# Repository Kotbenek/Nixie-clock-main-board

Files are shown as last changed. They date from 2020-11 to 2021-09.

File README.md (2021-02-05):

# Nixie-clock-main-board
Main PCB of my Nixie clock

## Board overview

- 12V AC input
- Rectified, smoothed 12V AC output (around 16V DC, powering the [180V power supply](https://github.com/Kotbenek/180V-power-supply))
- ATmega32 AVR microcontroller as the heart of the Nixie clock
- Photoresistor input for PWM Nixie tubes dimming
- Two inputs for external buttons used for timezone setting (UTC offset): TIMEZONE- and TIMEZONE+
- GPS module connector (3.3V, ground and GPS_TX line) with power on/off capability
- 6P6C connector used for interfacing the [Nixie clock tubes driver](https://github.com/Kotbenek/Nixie-clock-tubes-driver) board
- AVR ISP connector for AVR programming

## Images

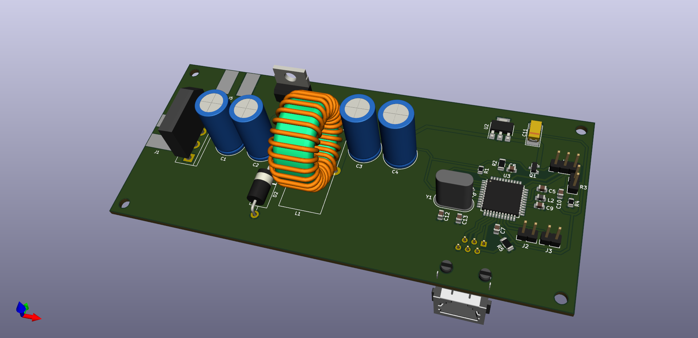
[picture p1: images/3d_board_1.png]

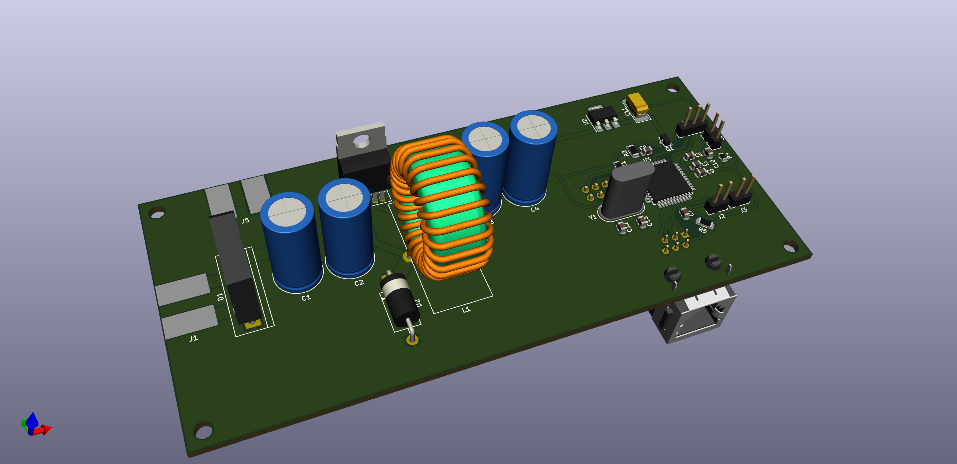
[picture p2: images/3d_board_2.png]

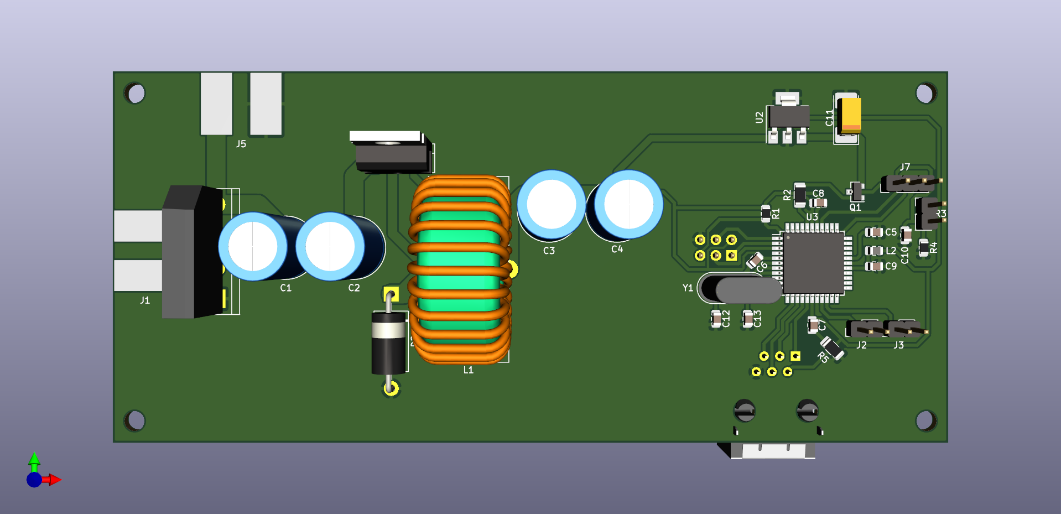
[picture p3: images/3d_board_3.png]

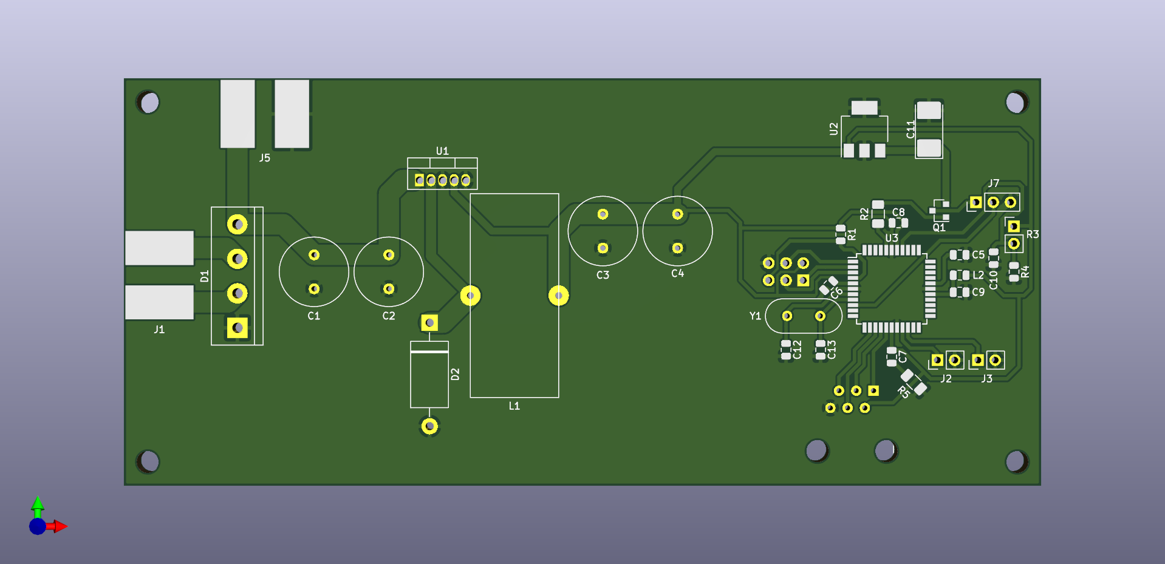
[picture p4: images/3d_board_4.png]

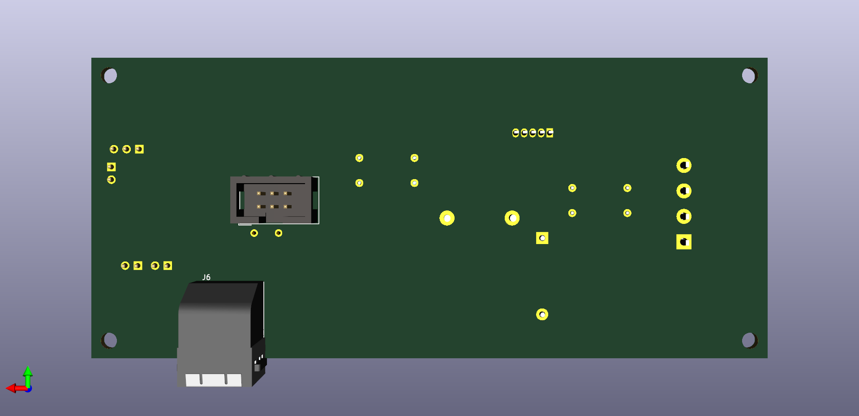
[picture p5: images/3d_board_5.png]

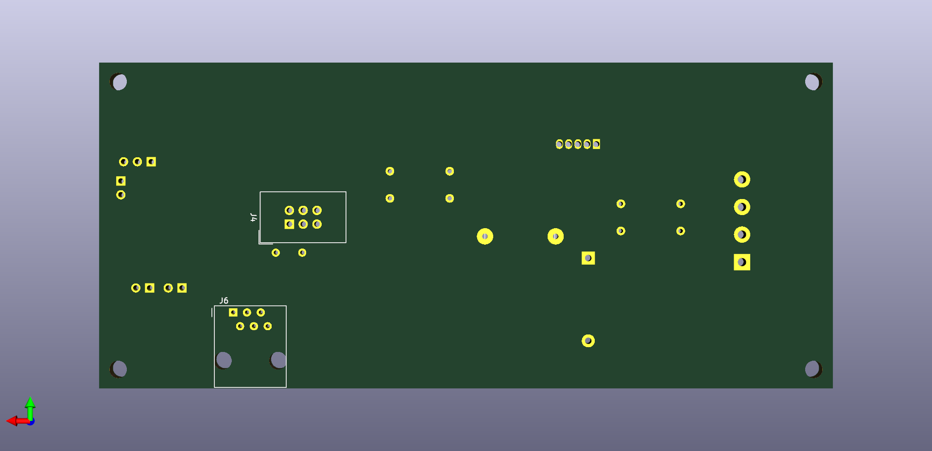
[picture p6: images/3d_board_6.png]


## External 3D models used in the PCB render

- [Bridge rectifier](https://grabcad.com/library/bridge-rectifier-kbp-case-1)
- [Toroid inductor](https://grabcad.com/library/inductor-toroid-25mm-1)
- [6P6C connector](https://grabcad.com/library/rj12-1)

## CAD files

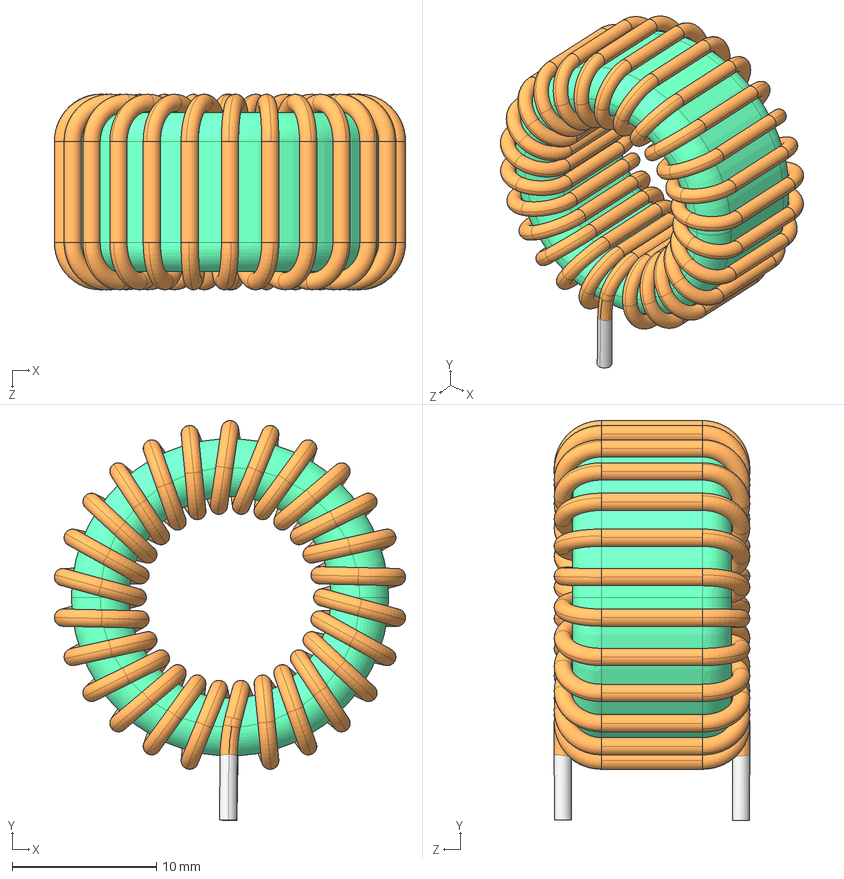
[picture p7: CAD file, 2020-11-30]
inductor.STEP
24.4 x 27.7 x 13.6 mm
櫻蠉錪1
櫻蠉錪3
櫻蠉錪2 x 50
櫻蠉錪4 x 2

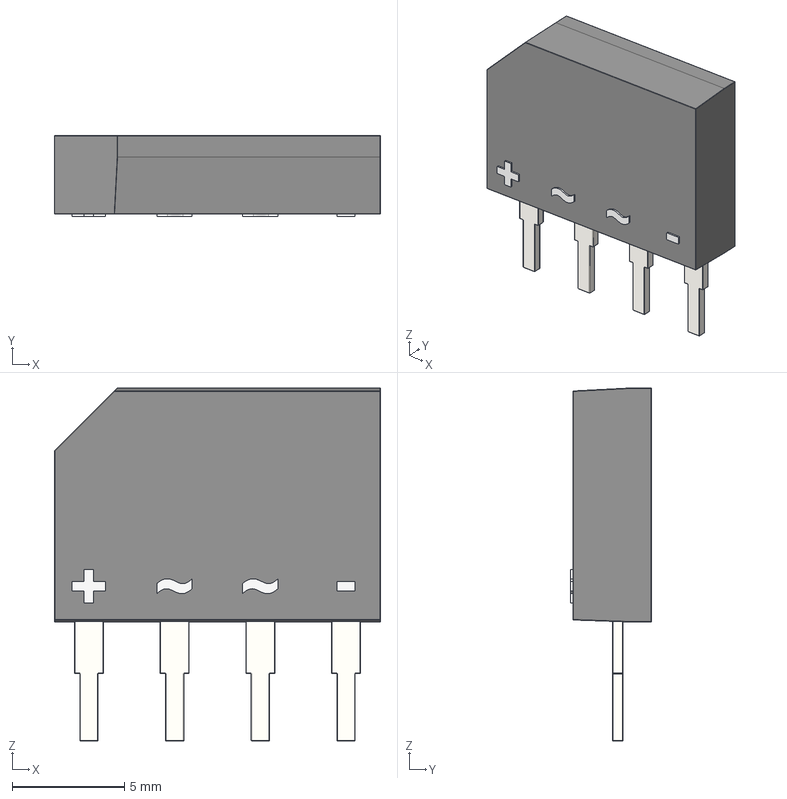
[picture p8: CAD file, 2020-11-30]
bridge.stp
14.5 x 3.60 x 15.7 mm

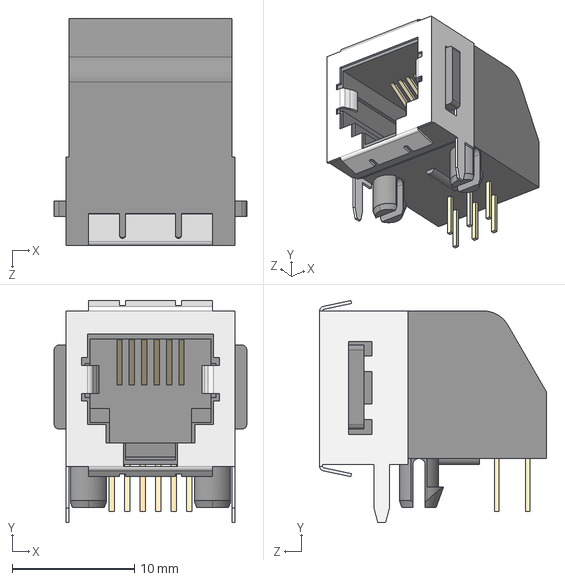
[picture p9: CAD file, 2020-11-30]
6p6c.stp
15.7 x 18.1 x 18.5 mm

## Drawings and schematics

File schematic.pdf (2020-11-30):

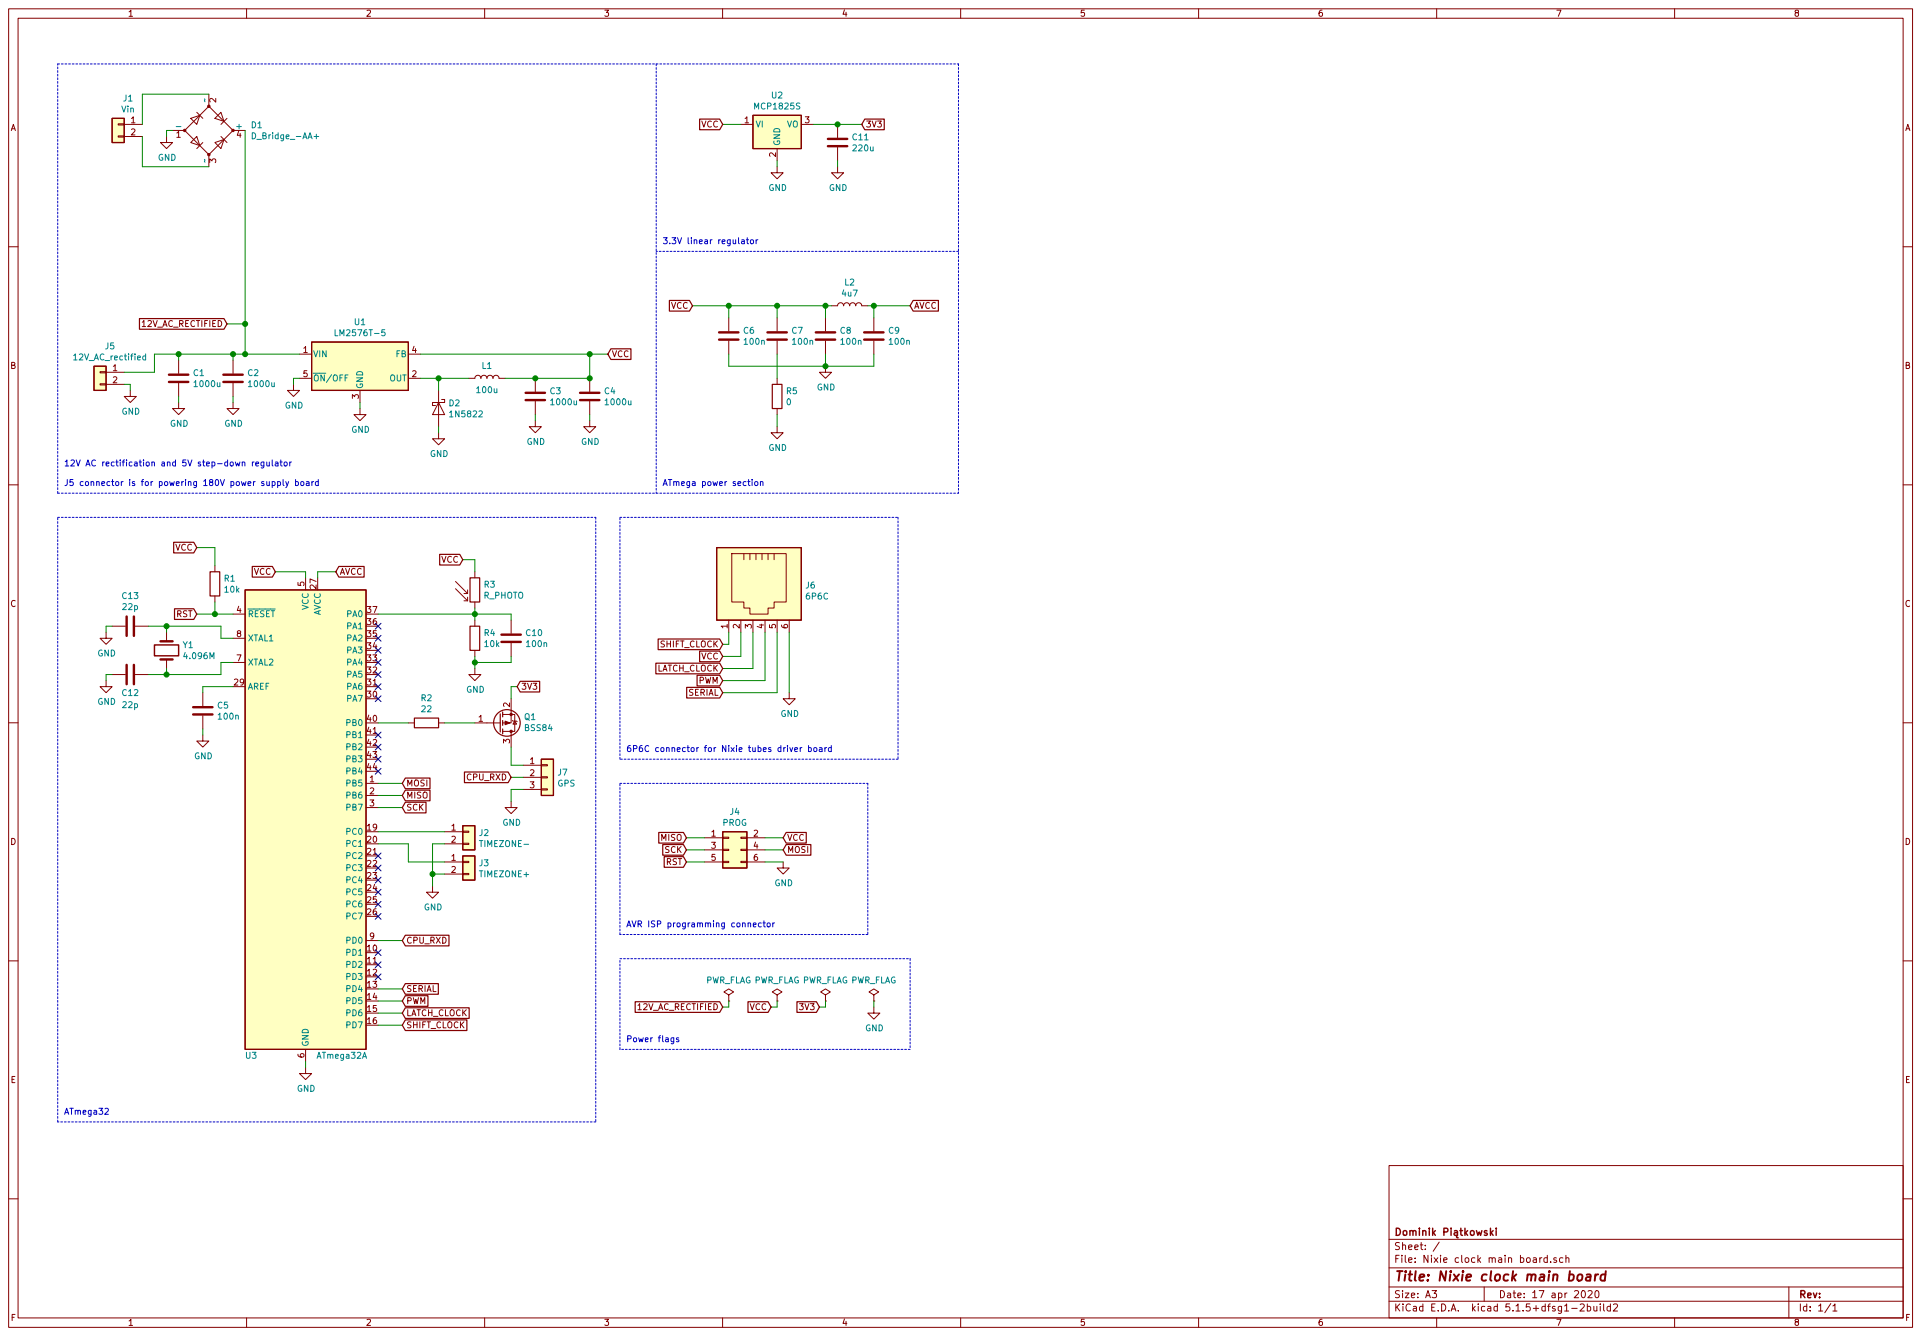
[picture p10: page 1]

3.3V linear regulator

ATmega power section | L2

12V AC rectification and 5V step-down regulator

J5 connector is for powering 180V power supply board

Power flags 6P6C connector for Nixie tubes driver board

AVR ISP programming connector

File: Nixie clock main board.sch Sheet: / Dominik Pitkowski

Id: 1/1 Title: Nixie clock main board

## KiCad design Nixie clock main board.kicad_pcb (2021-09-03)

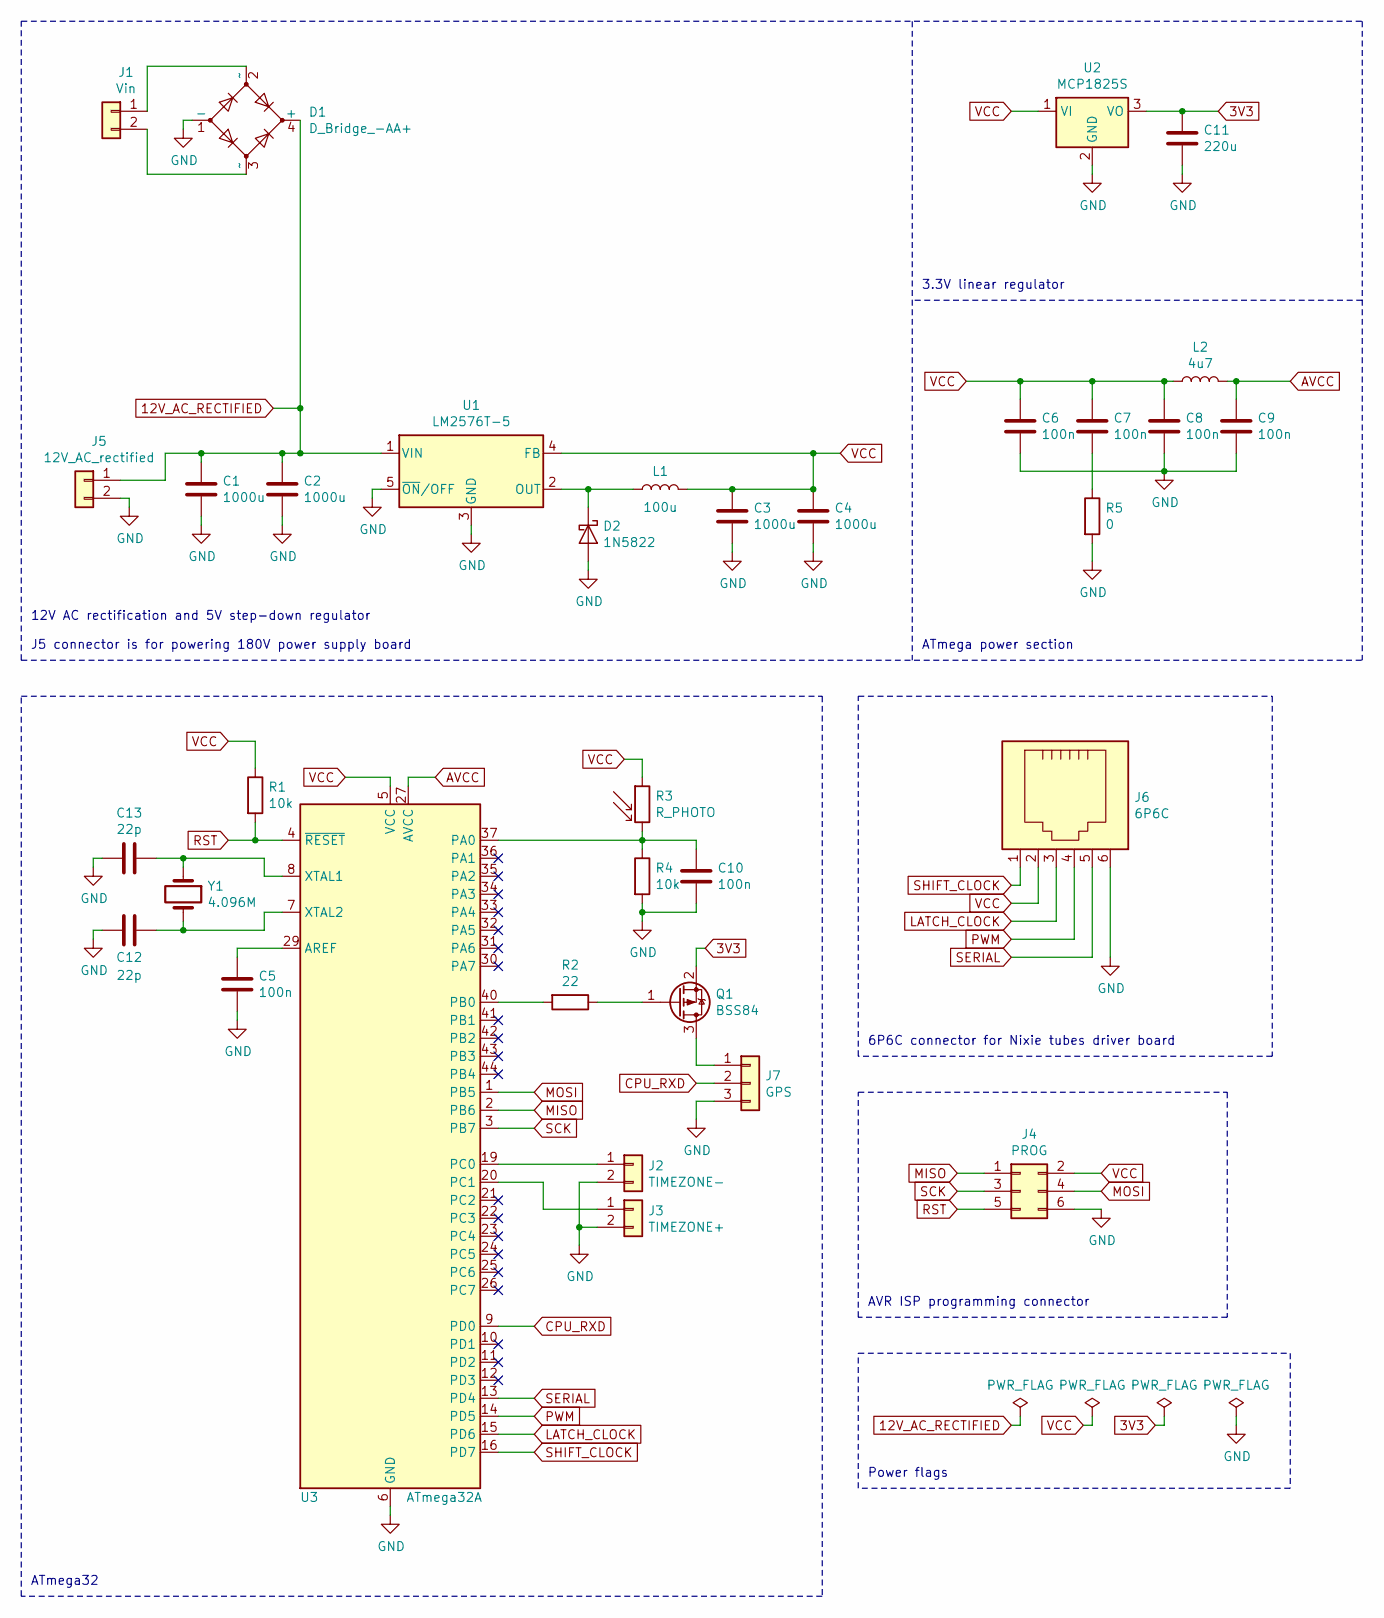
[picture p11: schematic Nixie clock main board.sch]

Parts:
C1, C2, C3, C4: 1000u; C_Radial_D10.0mm_H20.0mm_P5.00mm
C5, C6, C7, C8, C9, C10: 100n; C_0805_2012Metric
C11: 220u; CP_EIA-7132-28_AVX-C
C12, C13: 22p; C_0805_2012Metric
D1: D_Bridge_-AA+; TerminalBlock_bornier-4_P5.08mm
D2: 1N5822; D_DO-27_P15.24mm_Horizontal
J1: Vin; SolderWirePad_1x02_P3mm_10x5
J2: TIMEZONE-; PinHeader_1x02_P2.54mm_Vertical
J3: TIMEZONE+; PinHeader_1x02_P2.54mm_Vertical
J4: PROG; IDC-Header_2x03_P2.54mm_Vertical
J5: 12V_AC_rectified; SolderWirePad_1x02_P3mm_10x5
J6: 6P6C; RJ12_Amphenol_54601
J7: GPS; PinHeader_1x03_P2.54mm_Vertical
L1: 100u; L_Toroid_Vertical_L30mm_P13mm
L2: 4u7; L_0805_2012Metric
Q1: BSS84; SOT-23
R1, R4: 10k; R_0805_2012Metric
R2: 22; R_1206_3216Metric
R3: R_PHOTO; PinHeader_1x02_P2.54mm_Vertical
R5: 0; R_1206_3216Metric
U1: LM2576T-5; TO-220-5_Vertical
U2: MCP1825S; SOT-223-3_TabPin2
U3: ATmega32A; TQFP-44_10x10mm_P0.8mm
Y1: 4.096M; Crystal_HC49-U_Vertical

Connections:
3V3: C11.1, Q1.2 (S), U2.3 (VO)
12V_AC_RECTIFIED: C1.1, C2.1, D1.4 (+), J5.1, U1.1 (VIN)
AVCC: C9.1, L2.2, U3.27 (AVCC)
CPU_RXD: J7.2, U3.9 (PD0)
GND: C1.2, C2.2, C3.2, C4.2, C5.2, C6.2, C8.2, C9.2, C10.2, C11.2, C12.2, C13.2, D1.1 (-), D2.2 (A), J2.2, J3.2, J4.6, J5.2, J6.6, J7.3, R4.2, R5.2, U1.3 (GND), U1.5 (~ON~/OFF), U2.2 (GND), U3.6 (GND), U3.18 (GND), U3.28 (GND), U3.39 (GND)
LATCH_CLOCK: J6.3, U3.15 (PD6)
MISO: J4.1, U3.2 (PB6)
MOSI: J4.4, U3.1 (PB5)
unnamed: C5.1, U3.29 (AREF)
unnamed: C7.2, R5.1
unnamed: C10.1, R3.2, R4.1, U3.37 (PA0)
unnamed: C12.1, U3.7 (XTAL2), Y1.2
unnamed: C13.1, U3.8 (XTAL1), Y1.1
unnamed: D1.2 (~~), J1.1
unnamed: D1.3 (~~), J1.2
unnamed: D2.1 (K), L1.1, U1.2 (OUT)
unnamed: J2.1, U3.19 (PC0)
unnamed: J3.1, U3.20 (PC1)
unnamed: J7.1, Q1.3 (D)
unnamed: Q1.1 (G), R2.1
unnamed: R2.2, U3.40 (PB0)
PWM: J6.4, U3.14 (PD5)
RST: J4.5, R1.2, U3.4 (~RESET)
SCK: J4.3, U3.3 (PB7)
SERIAL: J6.5, U3.13 (PD4)
SHIFT_CLOCK: J6.1, U3.16 (PD7)
VCC: C3.1, C4.1, C6.1, C7.1, C8.1, J4.2, J6.2, L1.2, L2.1, R1.1, R3.1, U1.4 (FB), U2.1 (VI), U3.5 (VCC), U3.17 (VCC), U3.38 (VCC)

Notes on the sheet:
ATmega32
6P6C connector for Nixie tubes driver board
AVR ISP programming connector
Power flags
ATmega power section
3.3V linear regulator
12V AC rectification and 5V step-down regulator J5 connector is for powering 180V power supply board

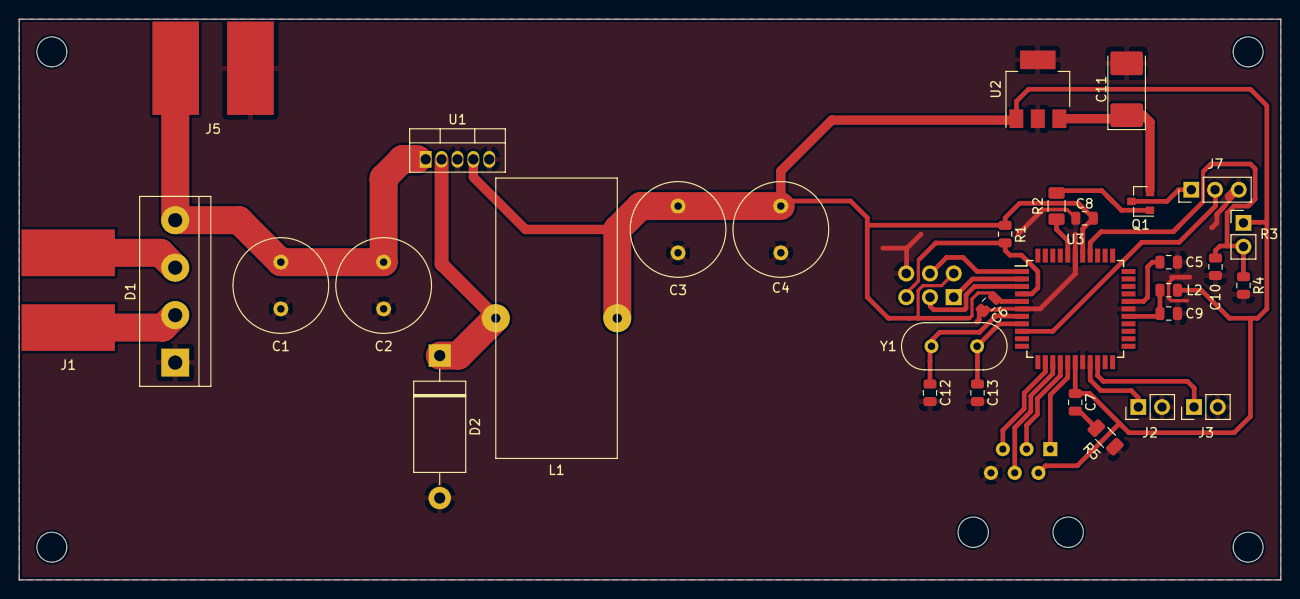
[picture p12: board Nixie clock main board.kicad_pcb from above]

Board: 2 copper layers, 135.0 x 60.0 mm, 38 parts (0 on the bottom side), 27 nets.

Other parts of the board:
3mm hole, 3mm hole#2, 3mm hole#3, 3mm hole#4: MountingHole_3.2mm_M3_DIN965

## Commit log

2020-11-30 Version 1.0
    [6p6c.stp, Nixie clock main board.kicad_pcb, Nixie clock main board.sch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]
2020-11-30 Added more PCB images
2020-11-30 Added gerber files
    [Nixie clock main board.kicad_pcb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]
2020-11-30 Added schematic as pdf file
2020-11-30 Added mounting holes
    [Nixie clock main board.kicad_pcb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]
2021-09-03 Added missing gerber files
    [Nixie clock main board.kicad_pcb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]
